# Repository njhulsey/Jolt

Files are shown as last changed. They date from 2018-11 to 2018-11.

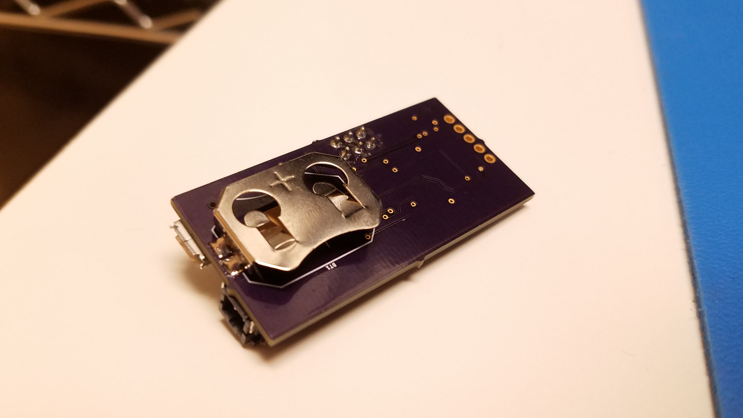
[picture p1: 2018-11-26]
Final_Photos/Assembled_Back.jpg

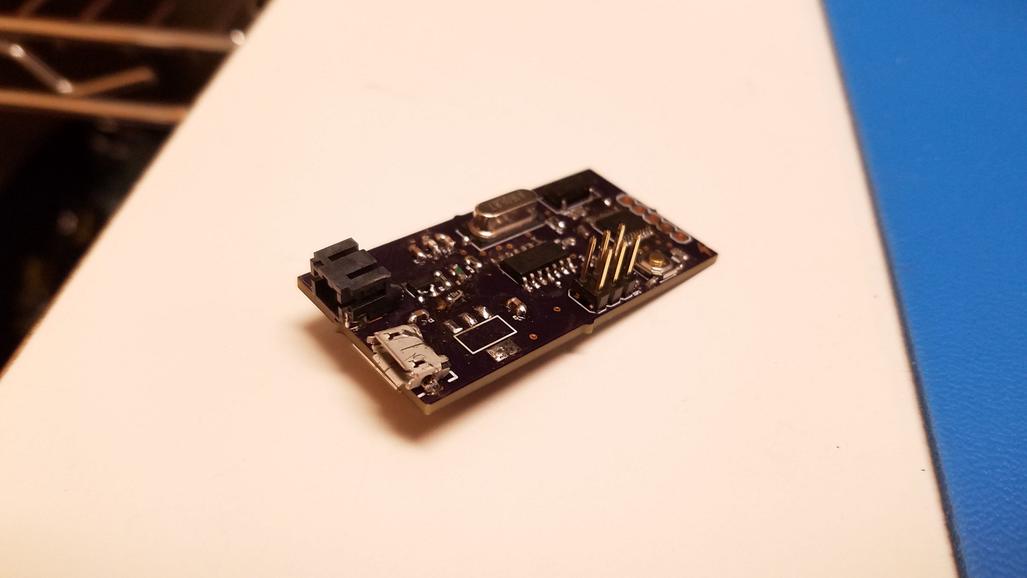
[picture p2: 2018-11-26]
Final_Photos/Assembled_Front.jpg

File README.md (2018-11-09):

# Jolt

Fall Semester of Sophomore year I was a part of a student organization called Generate which is Northeasterns student-led build studio. Generate works with clients to further their ideas. We provide a semesters worth of free engineering. My time in Generate has been primarily working as a build studio engineer meaning I help bring the client's idea to life. 

Jolt is one of the projects I worked on during my sophomore fall semester. Jolt is a wearable electronic alarm that shocks users awake. Throughout this project I helped build and design the PCB and schematic. I also worked in a team of engineers whom varried in mechanical, electrical, and computer engineering. All of the files I created and worked on can be found in this repository. 

What I learned while working on this project:
  - Interfacing with real time clocks
  - Charging circuits for LiPo batteries
  - PCB conventions
  - Schematic conventions
  - Reading datasheets
  - Picking parts
  - Team communication and effectiveness

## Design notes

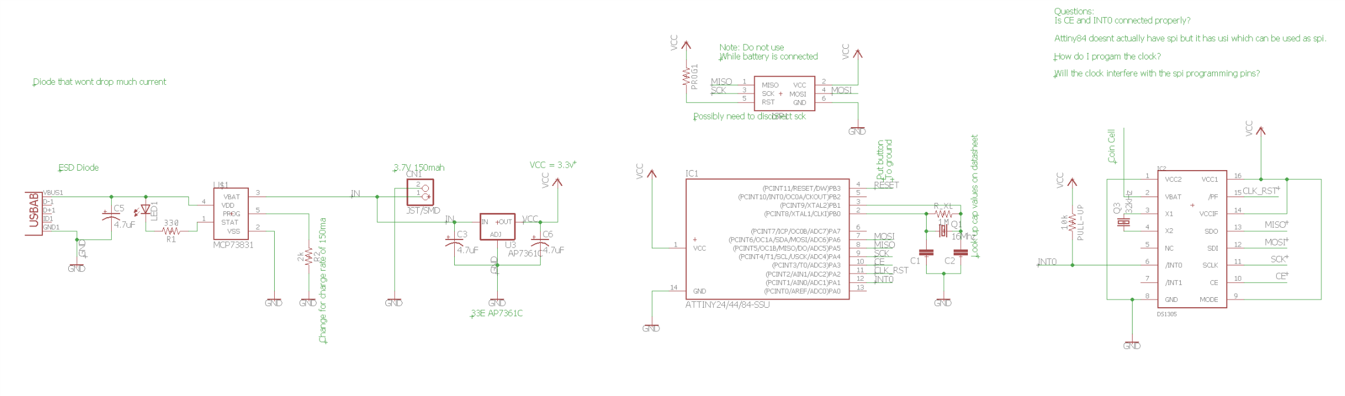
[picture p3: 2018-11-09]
Progress Photos/Schematic5.png

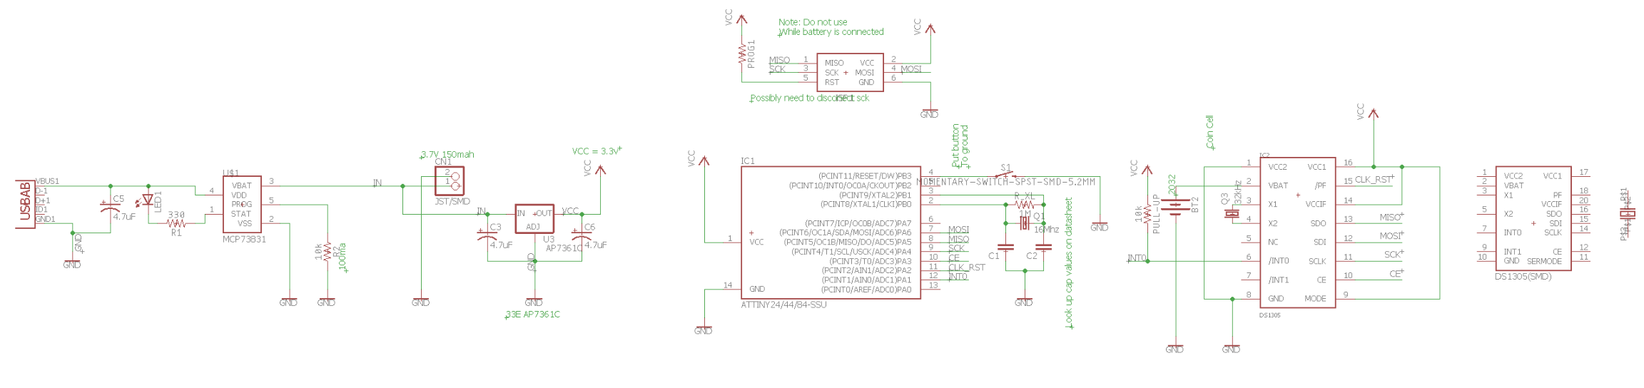
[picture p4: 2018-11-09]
Progress Photos/Schematic6.png

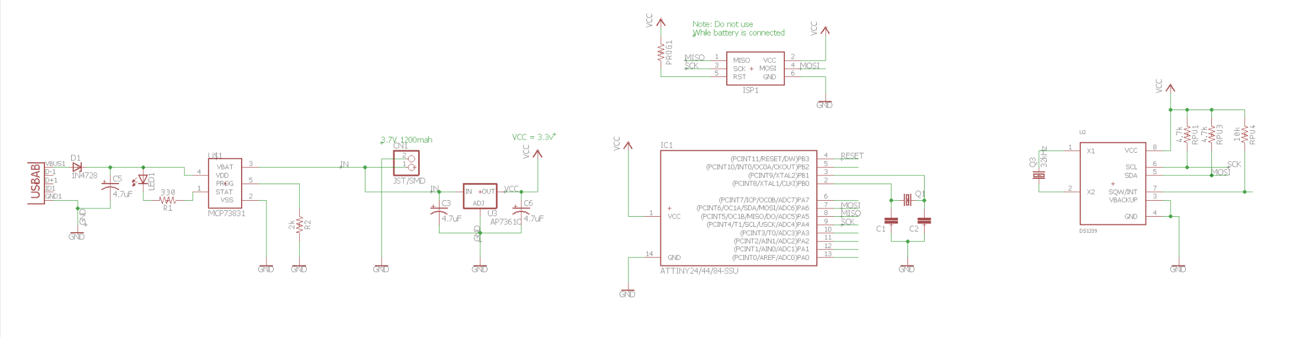
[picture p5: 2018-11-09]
Progress Photos/Schematic2.png

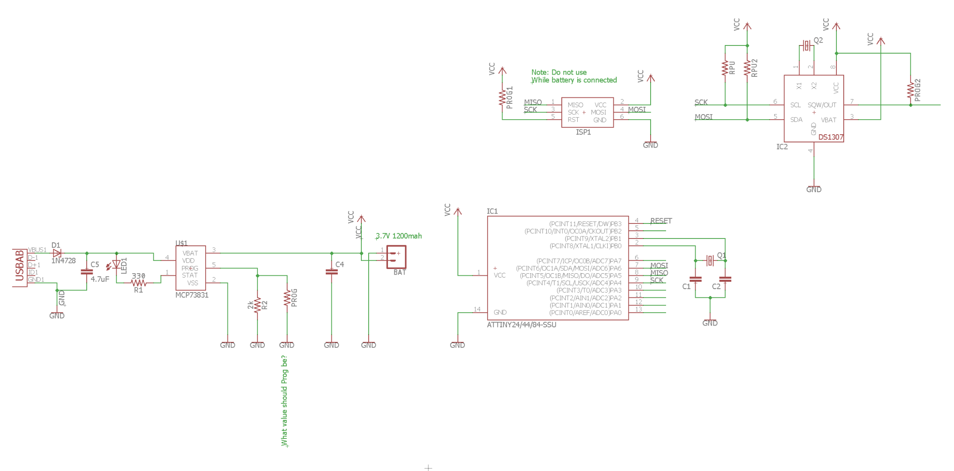
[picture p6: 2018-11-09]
Progress Photos/Schematic1.png

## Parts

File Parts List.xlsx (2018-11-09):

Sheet: THT
Parts List for Jolt | Last Updated: | 2018-10-28 | 20:34:00
Name: | Package Type: | Distributor | Amount | Cost (per 1) | Total Cost: | Description: | Link:
COM-08720 | SMD | Mouser | 10 | $0.95 | $9.50 | Push button for reset on attiny84 | https://www.mouser.com/ProductDetail/SparkFun/COM-08720?qs=WyAARYrbSnaaMDwitZjU3A%3D%3D
710-629105150921 (USB connector) | SMT | Mouser | 10 | $1.81 | $18.10 | Micro USB Connector AB | https://www.mouser.com/ProductDetail/Wurth-Electronics/629105150921
Lipo Battery | NA | Adafruit | 4 | $5.95 | $23.80 | 3.7v 150mAh w/ JST | https://www.adafruit.com/product/1317
MCP7381 12T | SMD | Mouser | 10 | $0.56 | $5.60 | Lipo charger | https://www.mouser.com/ProductDetail/Microchip-Technology/MCP73812T-420I-OT
JST Connector | SMD | Adafruit | 10 | $0.75 | $7.50 | JST-PH 2-Pin | https://www.adafruit.com/product/1769
AP7361C 33E | SMD | Mouser | 10 | $0.57 | $5.70 | 3.3v Regulator | https://www.mouser.com/ProductDetail/Diodes-Incorporated/AP7361C-33E-13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
ATtiny84A | SMD | Mouser | 10 | $0.81 | $8.10 | Microcontroller | https://www.mouser.com/ProductDetail/Microchip-Technology-Atmel/ATTINY84A-SSU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
ATtiny84A | THT | Mouser | 5 | $2.04 | $10.20 | Microcontroller | https://www.mouser.com/ProductDetail/Microchip-Technology-Atmel/ATTINY84-20PU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
DS1305 | THT | Digikey | 5 | $5.62 | $28.10 | RTC SPI Clock | https://www.digikey.com/product-detail/en/maxim-integrated/DS1305/DS1305-ND/869061
DS1305 | SMD | Digikey | 10 | $5.07 | $50.70 | RTC SPI Clock | https://www.digikey.com/product-detail/en/maxim-integrated/DS1305E/DS1305E-ND/869062
Crystal (for DS1305) | THT | Digikey | 5 | $0.54 | $2.70 | 32.768Khz Crystal 6pf | https://www.digikey.com/product-detail/en/epson/C-002RX-32.7680K-E-PBFREE/SER3205-ND/1022093
Crystal (for DS1305) | SMD | Digikey | 10 | $0.57 | $5.70 | 32.768Khz Crystal 6pf | https://www.digikey.com/product-detail/en/iqd-frequency-products/LFXTAL016178REEL/1923-1021-1-ND/8634031
Crystal (for ATtiny84) | SMD | Digikey | 10 | $0.27 | $2.70 | 16Mhz Crystal 18pf | https://www.digikey.com/product-detail/en/abracon-llc/ABLS-16.000MHZ-B4-T/535-10226-1-ND/2184261
BK-912 | SMD | Digikey | 10 | $0.44 | $4.40 | Coin cell 2032 Retainer | https://www.digikey.com/product-detail/en/BK-912/BK-912-ND/2647825?WT.z_cid=ref_netcomponents_dkc_buynow
2032 | NA | Digikey | 5 | $0.29 | $1.45 | Coin cell 2032 | https://www.digikey.com/product-detail/en/panasonic-bsg/CR2032/P189-ND/31939
5.6k Resistor | THT | Digikey | 10 | $0.24 | $2.40 | 5.6k Resistor | https://www.digikey.com/product-detail/en/vishay-bc-components/MBA02040C5601FCT00/BC3283CT-ND/6138786
0.022uF Cap | THT | Digikey | 10 | $0.21 | $2.15 | Cermaic, 50V 0.022uf | https://www.digikey.com/product-detail/en/kemet/C315C223K5R5TA7303/399-14089-1-ND/6562591
Switch | THT | Digikey | 10 | $0.42 | $4.16 | DPDT Slide Switch | https://www.digikey.com/product-detail/en/c-k/JS202011CQN/401-2001-ND/1640097
22uF Cap | THT | Digikey | 10 | $0.91 | $9.10 | Ceramic, 22uF, 16V | https://www.digikey.com/product-detail/en/tdk-corporation/FG11X7R1C226MRT06/445-173115-1-ND/5811720
0 Ohm Resistor | THT | Mouser | 30 | $0.17 | $5.10 | 0 ohm resistor for SPI | https://www.mouser.com/ProductDetail/Vishay/CRCW06030000Z0EAC
4.7uf SMD Caps | SMD | Digikey | 30 | $0.15 | $4.50 | 4.7uf SMD Cap | https://www.digikey.com/product-detail/en/samsung-electro-mechanics/CL10A475KP8NNNC/1276-1044-1-ND/3889130
TOTAL | 4 | 3 | 194 | $1.35 | $211.66
 |  |  |  |  | (for condensed board, you can go down to 0402 or even 0201 (although good luch hand placign those things……)
TODO: 0603
Caps | try to get standard ceramic 0603 caps
Resistors | standard 0603
LED | you can snag 0603 LEDs too….

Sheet: MechE Parts
Micro USB Connector | https://www.mouser.com/ProductDetail/Wurth-Electronics/629105150921
Battery | https://www.adafruit.com/product/1317
JST-PH 2-Pin (battery connector) | https://www.adafruit.com/product/1769
Coin cell 2032 Retainer | https://www.digikey.com/product-detail/en/BK-912/BK-912-ND/2647825?WT.z_cid=ref_netcomponents_dkc_buynow
Pin Header (2.54 mm Height) | https://www.google.com/search?q=pin+header&rlz=1C1CHBF_enUS744US744&tbm=isch&biw=1500&bih=859

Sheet: PCB Parts List
Name: | Order Status | Amount | Cost (per 1) | Total Cost: | Description: | Link:
COM-08720 | TRUE | 10 | $0.95 | $9.50 | Push button for reset on attiny84 | https://www.mouser.com/ProductDetail/SparkFun/COM-08720?qs=WyAARYrbSnaaMDwitZjU3A%3D%3D
710-629105150921 (USB connector) | TRUE | 10 | $1.81 | $18.10 | Micro USB Connector AB | https://www.mouser.com/ProductDetail/Wurth-Electronics/629105150921
MCP7381 12T | TRUE | 10 | $0.56 | $5.60 | Lipo charger | https://www.mouser.com/ProductDetail/Microchip-Technology/MCP73812T-420I-OT
JST Connector | TRUE | 10 | $0.75 | $7.50 | JST-PH 2-Pin | https://www.adafruit.com/product/1769
AP7361C 33E | TRUE | 10 | $0.57 | $5.70 | 3.3v Regulator | https://www.mouser.com/ProductDetail/Diodes-Incorporated/AP7361C-33E-13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
ATtiny84A | TRUE | 10 | $0.81 | $8.10 | Microcontroller | https://www.mouser.com/ProductDetail/Microchip-Technology-Atmel/ATTINY84A-SSU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
DS1305 | TRUE | 10 | $5.07 | $50.70 | RTC SPI Clock | https://www.digikey.com/product-detail/en/maxim-integrated/DS1305E/DS1305E-ND/869062
Crystal (for DS1305) | TRUE | 10 | $0.57 | $5.70 | 32.768Khz Crystal 6pf | https://www.digikey.com/product-detail/en/iqd-frequency-products/LFXTAL016178REEL/1923-1021-1-ND/8634031
Crystal (for ATtiny84) | TRUE | 10 | $0.27 | $2.70 | 16Mhz Crystal 18pf | https://www.digikey.com/product-detail/en/abracon-llc/ABLS-16.000MHZ-B4-T/535-10226-1-ND/2184261
BK-912 | TRUE | 10 | $0.44 | $4.40 | Coin cell 2032 Retainer | https://www.digikey.com/product-detail/en/BK-912/BK-912-ND/2647825?WT.z_cid=ref_netcomponents_dkc_buynow
0 Ohm Resistor | TRUE | 30 | $0.17 | $5.10 | 0 ohm resistor for SPI | https://www.mouser.com/ProductDetail/Vishay/CRCW06030000Z0EAC
4.7uf SMD Caps | TRUE | 30 | $0.15 | $4.50 | 4.7uf SMD Cap | https://www.digikey.com/product-detail/en/samsung-electro-mechanics/CL10A475KP8NNNC/1276-1044-1-ND/3889130
18pf smd cap | TRUE | 30 | $0.28 | $8.40 | 18pf smd cap | https://www.mouser.com/ProductDetail/KEMET/C0603C180K5RACAUTO
330 Ohm Resistor | TRUE | 30 | $0.15 | $4.50 | 330 Ohm Resistor | https://www.mouser.com/ProductDetail/KOA-Speer/SG73G1JTTD3300D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
1M resistor | TRUE | 30 | $0.17 | $5.10 | 1M resistor | https://www.mouser.com/ProductDetail/Vishay/CRCW06031M00FKEAC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
10k resistor | TRUE | 30 | $0.17 | $5.10 | 10k resistor | https://www.mouser.com/ProductDetail/Vishay/CRCW060310K0FKEAC
47 resistor | TRUE | 30 | $0.10 | $3.00 | 47 resistor | https://www.digikey.com/product-detail/en/panasonic-electronic-components/ERJ-3GEYJ470V/P47GCT-ND/62691
100k resistor | TRUE | 30 | $0.10 | $3.00 | 100k resistor | https://www.digikey.com/product-detail/en/bourns-inc/CR0603-JW-104ELF/CR0603-JW-104ELFCT-ND/3767631
 |  |  |  | $156.70

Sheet: Shock breakoff
Name: | Package Type: | Distributor | Amount | Cost (per 1) | Total Cost: | Description: | Link:
AVT50-1.0K-ND |  | Digikey | 3 | $7.56 | $22.68 | RES ADJ 1.0K OHM 50W 10% LUGS | https://www.digikey.com/product-detail/en/vishay-huntington-electric-inc/AVT05006E1K000KE/AVT50-1.0K-ND/257637

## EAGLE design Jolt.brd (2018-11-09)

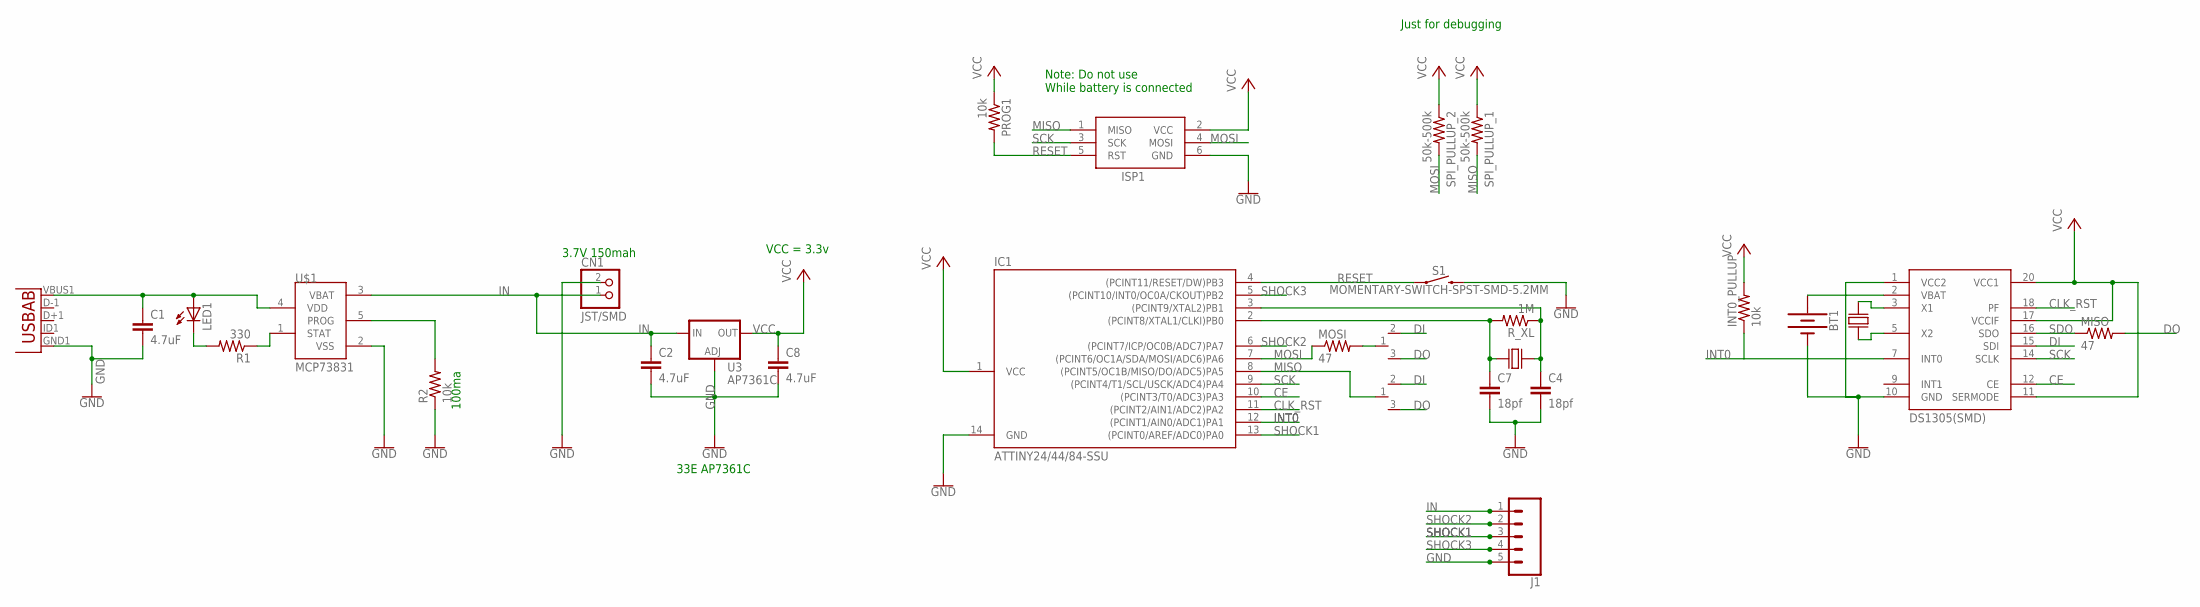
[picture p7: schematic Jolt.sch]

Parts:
BT1: BATTERY-20MM_SMD_4LEGS_OVERPASTE; BATTCON_20MM_4LEGS_OVERPASTE
C1, C2, C8: 4.7uF; C0603K
C4, C7: 18pf; 0603
CN1: JST/SMD; JST-PH-2-SMT
IC1: ATTINY24/44/84-SSU; SOIC14
INT0_PULLUP: 10k; R0603
ISP1: AVRISP-6; AVRISP
J1: CONN_05; 1X05
LED1: LEDCHIPLED_0603; CHIPLED_0603
MISO: 47; R0603
MOSI: 47; R0603
PROG1: 10k; R0603
R1: 330; R0603
R2: 10k; R0603
R_XL: 1M; R0603
S1: MOMENTARY-SWITCH-SPST-SMD-5.2MM; TACTILE_SWITCH_SMD_5.2MM
SPI_PULLUP_1, SPI_PULLUP_2: 50k-500k; R0603
U1: USB""; USB-MICRO-SMD
U3: AP7361C; SOT223
U$1: MCP73831; SOT23-5L
U$2: DS1305(SMD); TSSOP
U$3: CRYSTAL_SOJ; SOJ-4-5.5MM
U$4, U$5: 0603_SMD_JUMPER
U$6: CRYSTAL-SMD-HC-49US; CRYSTAL_SMD_HC-49/US

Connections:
CE: IC1.10 ((PCINT3/T0/ADC3)PA3), U$2.12 (CE)
CLK_RST: IC1.11 ((PCINT2/AIN1/ADC2)PA2), U$2.18 (PF)
DI: U$2.15 (SDI), U$4.2 (O2), U$5.2 (O2)
DO: MISO.2, U$4.3 (O1), U$5.3 (O1)
GND: BT1.2 (-), C1.2, C2.2, C4.2, C7.2, C8.2, CN1.2 (1), IC1.14 (GND), ISP1.6 (GND), J1.5, R2.1, S1.3 (2), U1.GND1 (GND), U3.1 (ADJ), U$1.2 (VSS), U$2.1 (VCC2), U$2.10 (GND)
IN: C2.1, CN1.1 (2), J1.1, U3.3 (IN), U$1.3 (VBAT)
INT0: IC1.12 ((PCINT1/AIN0/ADC1)PA1), INT0_PULLUP.1, U$2.7 (INT0)
MISO: IC1.8 ((PCINT5/OC1B/MISO/DO/ADC5)PA5), ISP1.1 (MISO), SPI_PULLUP_1.2, U$5.1 (IN)
MOSI: IC1.7 ((PCINT6/OC1A/SDA/MOSI/ADC6)PA6), ISP1.4 (MOSI), MOSI.1, SPI_PULLUP_2.2
unnamed: C1.1, LED1.A, U1.VBUS1 (VBUS), U$1.4 (VDD)
unnamed: MOSI.2, U$4.1 (IN)
unnamed: R1.1, U$1.1 (STAT)
unnamed: LED1.C, R1.2
unnamed: R2.2, U$1.5 (PROG)
unnamed: C7.1, IC1.2 ((PCINT8/XTAL1/CLKI)PB0), R_XL.2, U$6.P$2
unnamed: C4.1, IC1.3 ((PCINT9/XTAL2)PB1), R_XL.1, U$6.P$1
unnamed: BT1.1 (+), U$2.2 (VBAT)
unnamed: U$2.5 (X2), U$3.P$3
unnamed: U$2.3 (X1), U$3.P$1
RESET: IC1.4 ((PCINT11/RESET/DW)PB3), ISP1.5 (RST), PROG1.2, S1.1
SCK: IC1.9 ((PCINT4/T1/SCL/USCK/ADC4)PA4), ISP1.3 (SCK), U$2.14 (SCLK)
SDO: MISO.1, U$2.16 (SDO)
SHOCK1: IC1.13 ((PCINT0/AREF/ADC0)PA0), J1.3
SHOCK2: IC1.6 ((PCINT7/ICP/OC0B/ADC7)PA7), J1.2
SHOCK3: IC1.5 ((PCINT10/INT0/OC0A/CKOUT)PB2), J1.4
VCC: C8.1, IC1.1 (VCC), INT0_PULLUP.2, ISP1.2 (VCC), PROG1.1, SPI_PULLUP_1.1, SPI_PULLUP_2.1, U3.2 (OUT), U$2.11 (SERMODE), U$2.17 (VCCIF), U$2.20 (VCC1)

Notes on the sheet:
Note: Do not use While battery is connected
VCC = 3.3v
3.7V 150mah
33E AP7361C
100ma
Just for debugging

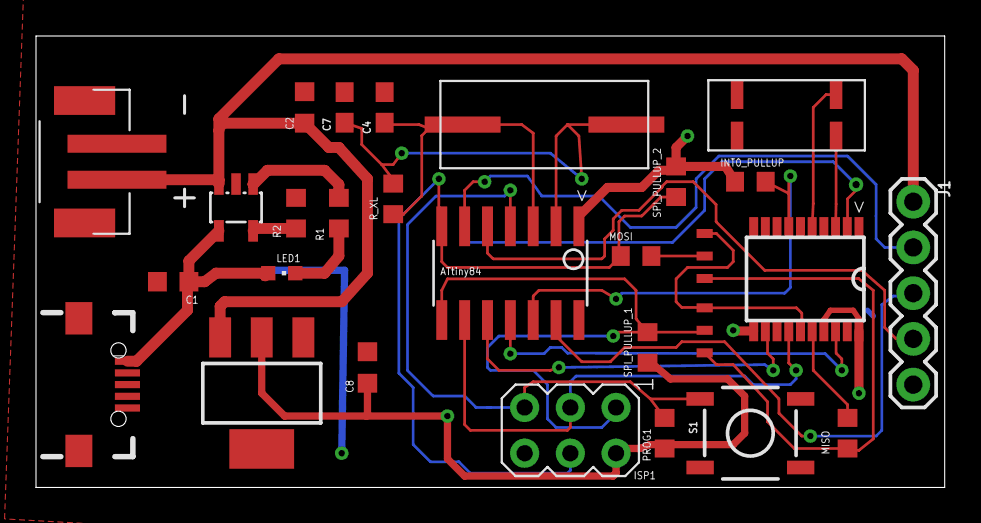
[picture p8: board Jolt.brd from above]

Board: 2 copper layers, 50.5 x 25.1 mm, 29 parts (1 on the bottom side), 26 nets.

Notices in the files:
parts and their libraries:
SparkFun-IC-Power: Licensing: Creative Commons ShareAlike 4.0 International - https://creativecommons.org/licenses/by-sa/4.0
